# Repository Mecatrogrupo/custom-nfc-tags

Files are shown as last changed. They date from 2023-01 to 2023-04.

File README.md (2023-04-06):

<!--- [![PÁGINA WEB](https://img.shields.io/badge/P%C3%81GINA%20WEB-21759B?style=for-the-badge&logo=WordPress&logoColor=white)](http://mecatrogrupo.com) --->




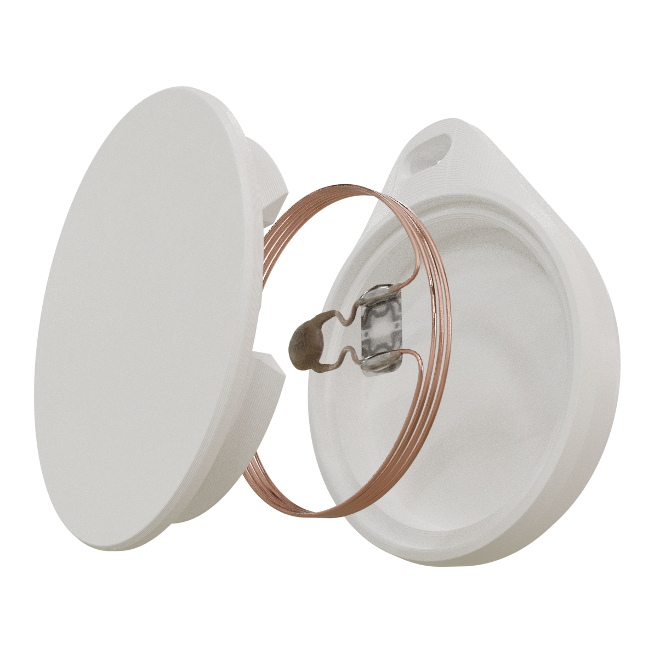
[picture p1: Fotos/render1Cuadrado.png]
Foto explotada llavero


## Objetivo
Lograr convertir diferentes tarjetas NFC dispositivos más pequeños que cumplan las mismas funciónes, como llaveros o pulseras. Esto incluye: extraer los chips y armarles otra carcasa, clonar tarjetas a otros formatos, combinar diferentes tecnologías en una, diseñar métodos para hacerlo en masa, y documentar los hallazgos en general.

## Hallazgos sobre diferentes sistemas
### Transporte argentino
Las tarjetas que usa son del tipo Mifare 1k. Guardan su saldo adentro y, al estar encriptadas, no pueden ser clonadas (o al menos no fácilmente). Su comunicación se define en [ISO 14443](https://www.iso.org/obp/ui/#iso:std:iso-iec:14443:-4:ed-4:v1:en) y trabaja a 13.56MHz. Sin embargo, en la práctica los lectores de transporte oscilan entre 14 y 15 MHz, y hay diferencias pronunciadas entre los diferentes métodos de transporte [[1]](#1).

Las tarjetas pueden ser leídas por teléfonos, pero testear antenas armadas con los mismos no es una buena indicación de la distancia en que las leerá un lector de transporte (por la diferencia de frecuencias y de diámetros del bobinado).

Los chips internos hasta el 2022 venían en dos tamaños: 7,5mm x 5mm y 6mm x 3mm. En 2023 se agregaron unos un poco más grandes.

#### Referencias

<a id="1">[1]</a> 
[ST AN2866 Application note](https://www.st.com/content/ccc/resource/technical/document/application_note/d9/29/ad/cc/04/7c/4c/1e/CD00221490.pdf/files/CD00221490.pdf/jcr:content/translations/en.C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)

## Diseño circular de llavero
Este diseño de llavero se basa en un cuerpo con un disco interno con el chip de la tarjeta, una bobina de cobre esmaltado, y un capacitor. Este último es necesario para lograr que la antena resuene bien a la frecuencia de los lectores, ya que seleccionar el alambre justo con la cantidad de vueltas justa es mucho más difícil y resulta en una distancia de lectura menor. \
Probamos hacer variantes *print in place* (se imprime el cuerpo hasta la mitad y después se coloca el llavero) y no *print in place* (se imprimen por separado y conectan a presión). Encontramos que la segunda es mucho más fácil de armar y no presenta desventajas considerables (solo queda un poquito más grande). \
Hay instrucciones de armado usando el ejemplo de transporte Argentino en [/Manuales/Instrucciones-maker.pdf](/Manuales/Instrucciones-maker.pdf).

### Medias testeadas que funcionan
*foto con las diferentes medidas*

n: cantidad de vueltas \
l: largo del alambre \
d: diámetro del alambre \
D: diámetro de la bobina \
H: altura espacio para bobinado \
h1: grosor de la tapa inferior \
h2: grosor de la tapa superior \
L: distancia de lectura relativa a la original \
F: medida del capacitor

#### Transporte argentino
| n | l | d | D | H | h1 | h2 | L | F |
|---|---|---|---|---|---|---|---|---|
| 7 | ~ 69cm | 0,25 mm | 25mm | ~35mm | 0.6mm | 1.15mm | buena | 39pF |

<hr />
<table border="0px">
<th align="left">
Mecatrogrupo 2022.
</th>
<tr>
<td>
Esta fuente describe Hardware Libre y está licenciada bajo la licencia 
CERN-OHL-W v2
</td>
</tr>
<tr>
<td>
Puede redistribuir y modificar esta documentación y crear productos
que la utilicen bajo los términos del CERN-OHL-W v2 (https:/cern.ch/cern-ohl).
Esta documentación se distribuye SIN NINGUNA GARANTÍA EXPRESA O IMPLÍCITA
GARANTÍA, INCLUIDA LA DE COMERCIABILIDAD, CALIDAD SATISFACTORIA
E IDONEIDAD PARA UN FIN DETERMINADO. Por favor refiérase a la CERN-OHL-W v2
para condiciones aplicables.<br/>
Ubicación de la fuente: https://github.com/Mecatrogrupo/custom-nfc-tags/
</td>
</tr>
</table>

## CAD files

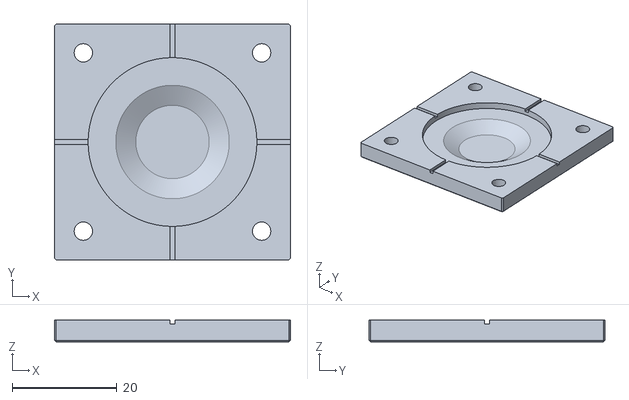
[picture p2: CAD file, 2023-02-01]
Modelos 3D/Sostenedor-de-disco.stl
45.0 x 45.0 x 4.15

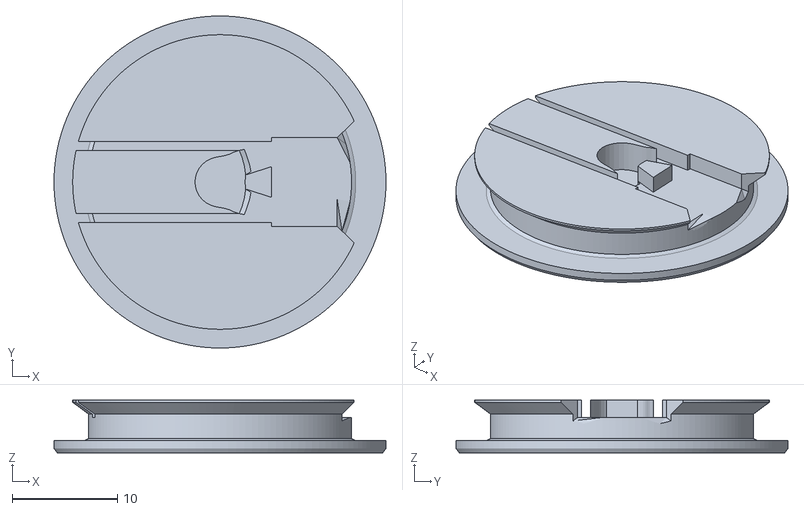
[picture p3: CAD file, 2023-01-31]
Modelos 3D/Disco.stl
31.5 x 31.5 x 4.99

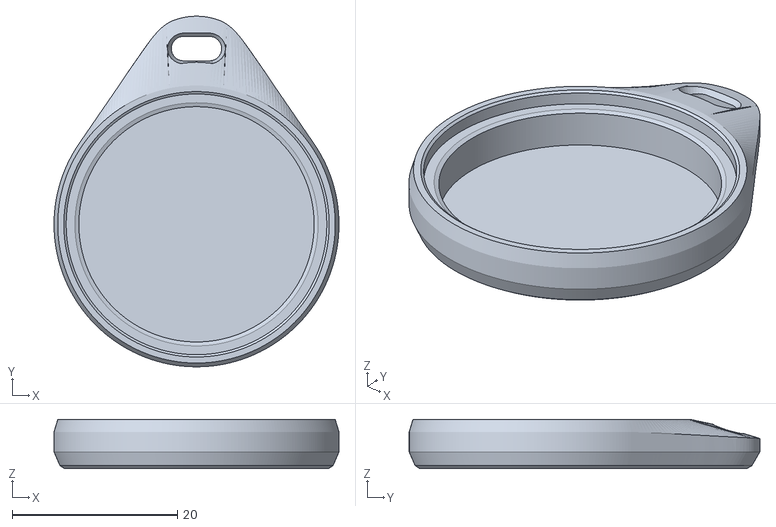
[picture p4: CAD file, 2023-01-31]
Modelos 3D/Cuerpo.stl
34.5 x 42.4 x 5.95

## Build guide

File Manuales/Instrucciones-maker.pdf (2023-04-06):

Llavero de Transporte - Kit Maker

## Instrucciones de armado

# ⓿ PARTES INCLUÍDAS

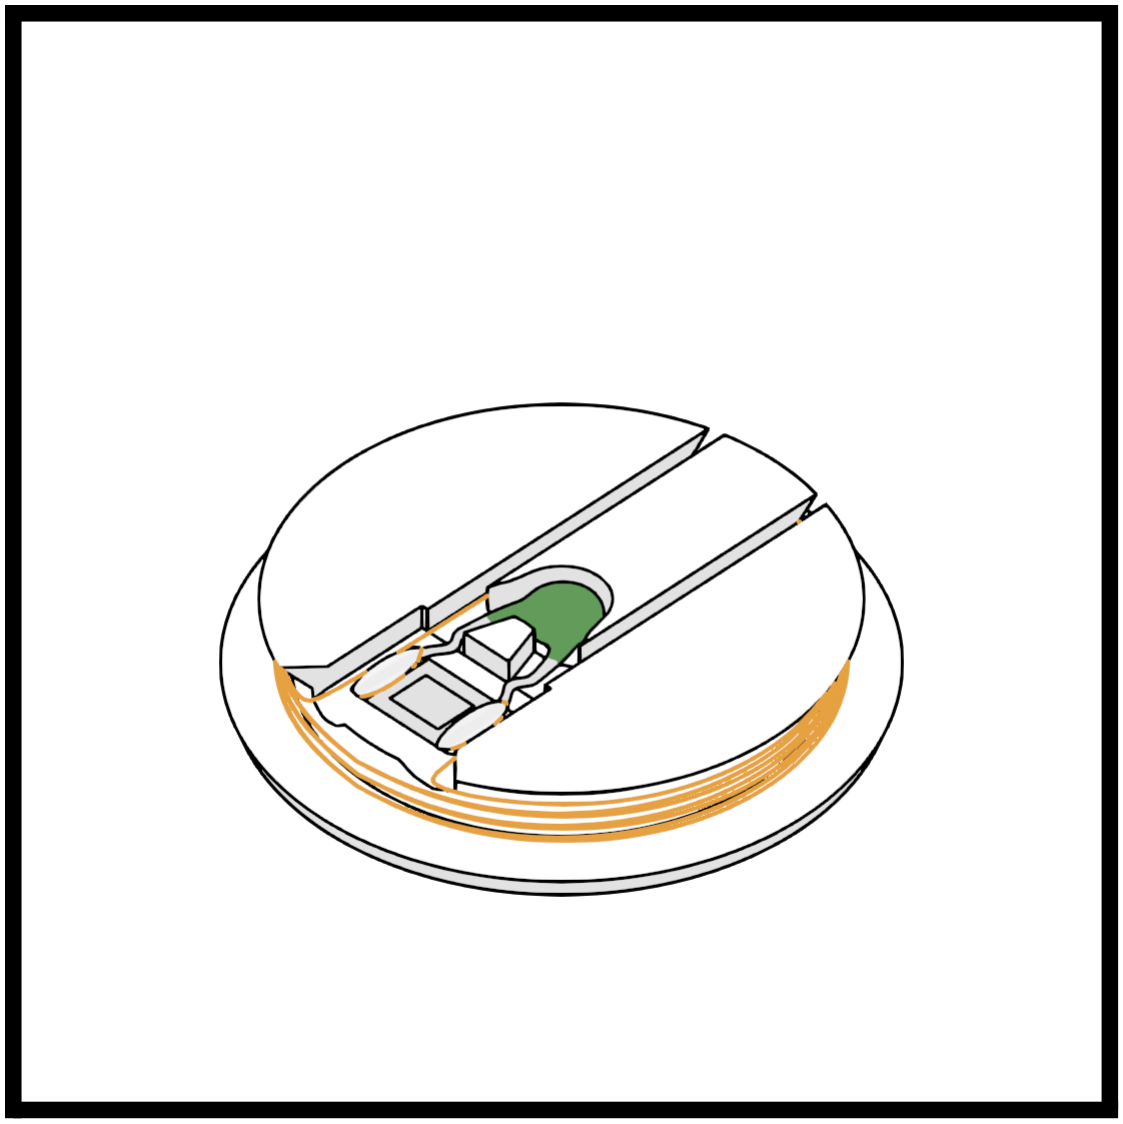
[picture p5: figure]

Disco | Cuerpo | Mosquetón

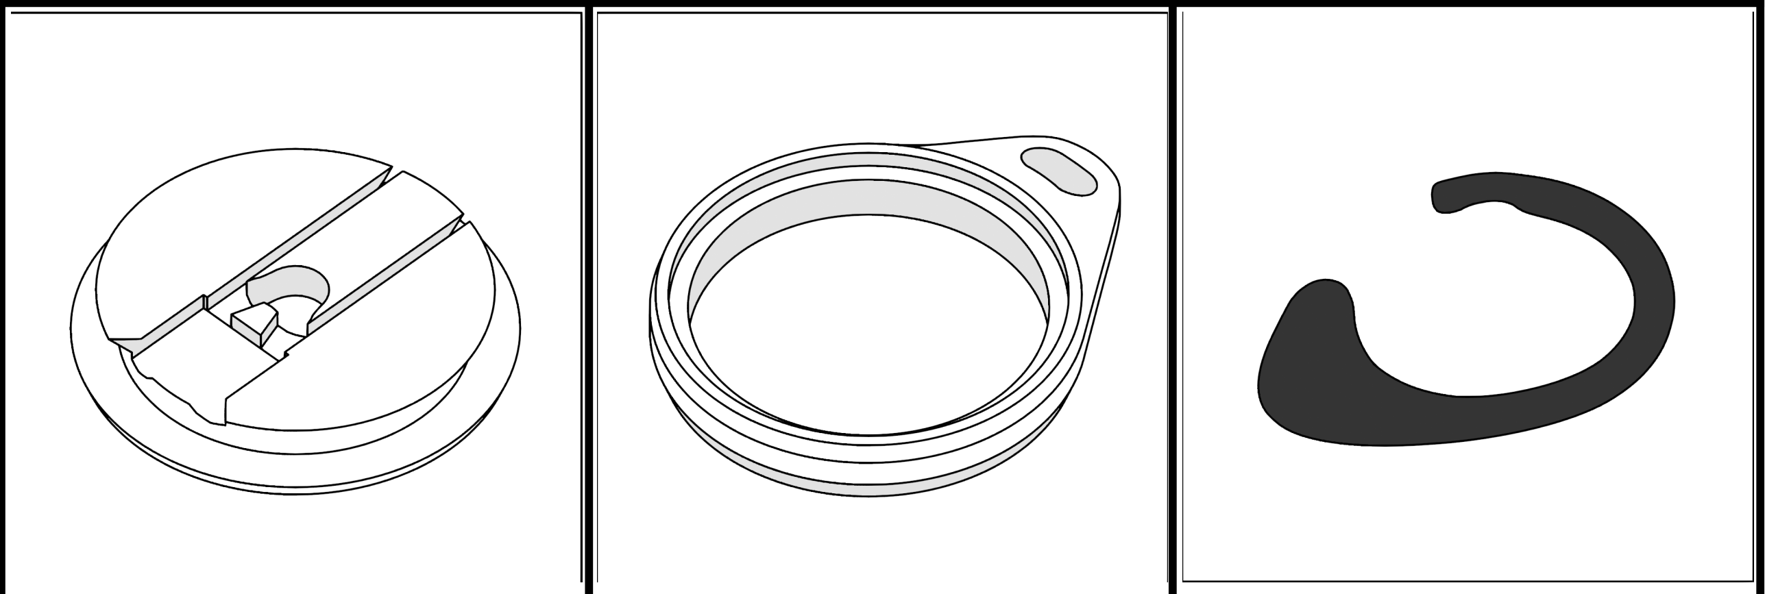
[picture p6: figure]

Cadena | Alambre | Capacitor

1

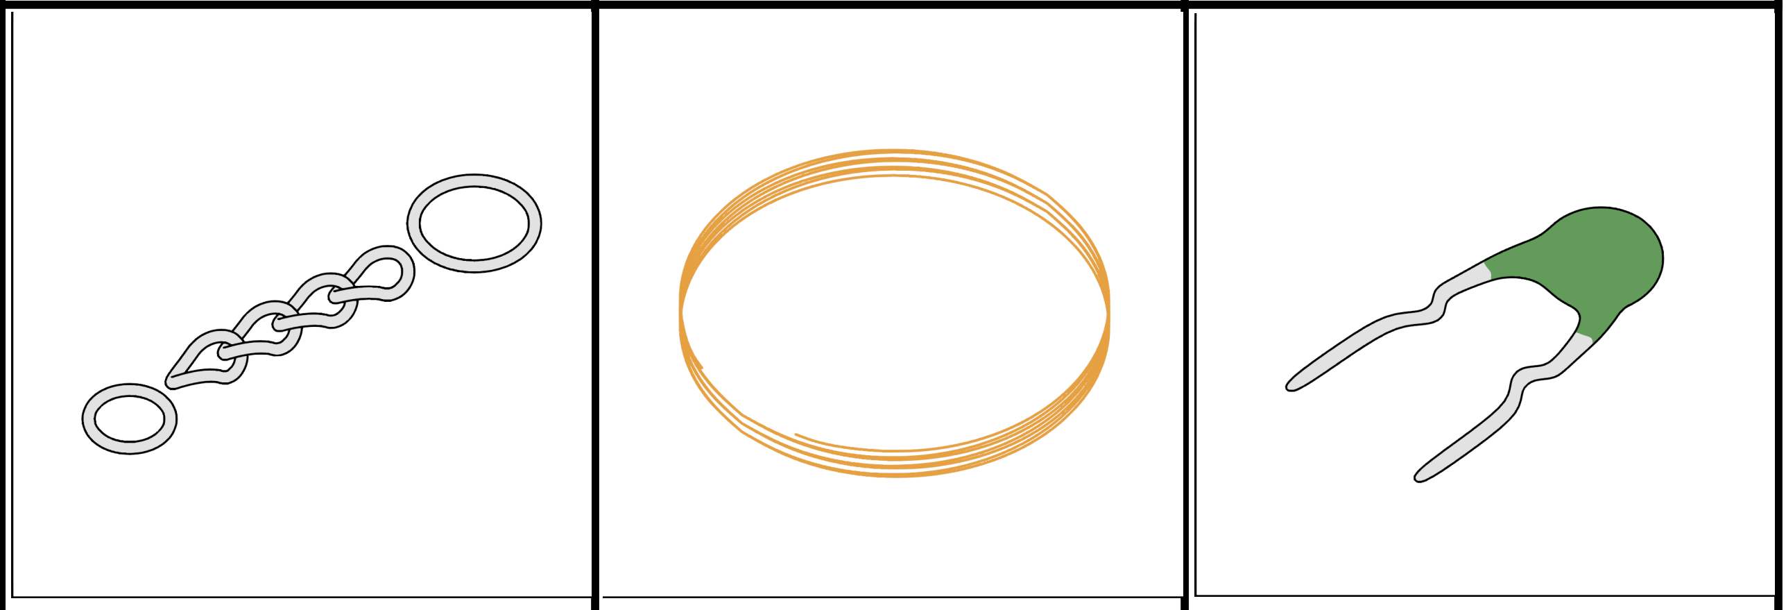
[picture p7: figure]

## Instrucciones de armado

# ❶ EXTRAER EL CHIP DE LA TARJETA

## Ⓐ Preparar la tarjeta

1. Anotar el número de la tarjeta para evitar perderlo
2. Mirar la tarjeta a contraluz con una linterna para encontrar el chip, suele estar en la esquina inferior derecha.
3. Marcar la zona del chip con un marcador.

## Ⓑ Recortar el chip

1. Con una tijera o alicate, cortar el pedazo del plástico donde se encuentra el chip. Hacerlo al ras, ya que alrededor del chip las capas de plástico están menos pegadas.

## Ⓒ Disolver el plástico

1. En un pequeño recipiente de vidrio o metal poner el pedazo de plástico y suficiente disolvente* como para taparlo.
2. Dejar disolver entre 20 mins. y 3 horas, agitando y limpiando residuos cada tanto.
3. Separar el chip con cuidado y sumergirlo en agua para no tocar la acetona.
4. Raspar las patas del chip con algo filoso, para que no quede ningún residuo.
Como disolvente sirven los quitaesmaltes con acetato de etilo, la acetona pura, o cualquier otro disolvente para PVC *

2

## Instrucciones de armado

# ❷ ARMAR LA BOBINA

## Ⓐ Enrollar la bobina

1. Enganchar una punta del alambre a una de las ranuras del disco, extendiéndolo hacia el espacio del chip.
2. Darle 7 vueltas al disco con el alambre, asegurarse que las puntas queden en el lugar donde se va a poner el chip. Trabar la punta del alambre en la segunda ranura.
3. Posicionar el capacitor en su lugar, de manera tal que las patitas traben el alambre para que no se salga.

## Ⓑ Desesmaltar las puntas

Si no tiene experiencia, recomendamos que practique los siguientes pasos con un pedacito sobrante de alambre.
1. Marcar dónde iría el chip para saber hasta donde desesmaltar.
2. Sacar el alambre del disco y quemar con un encendedor las puntas.
3. Lijar la parte quemada hasta que ya no se vea negra.
4. (Opcional) Usar un tester para probar continuidad.

## Ⓒ Estañar las puntas

1. Con un soldador, derretir estaño* en las puntas del alambre. Deberían quedar plateadas.
2. Si el estaño no pega, puede que no estén bien desesmaltadas. Repetir el punto B.

Recomendamos usar estaño con flux *

3

## Instrucciones de armado

# ❸ SOLDAR LOS COMPONENTES

## Ⓐ Preparar los componentes

1. Insertar el chip por debajo de las patas del capacitor.
2. Asegurarse de que las patas del capacitor y las puntas del alambre estén en contacto con los bordes del chip (los pads plateados).

Las patas del capacitor pueden doblarse para que queden en la posición correcta*

## Ⓑ Soldar los componentes

1. Soldar cada lado del chip con su respectiva punta del alambre y pata del capacitor.
2. Probar leer el disco con un teléfono con NFC o una terminal de carga.
3. Si no funciona, volver a soldar.

No apoyar el soldador durante mucho tiempo, ya que puede sobrecalentar los componentes*

4

## Instrucciones de armado

# ❹ ARMAR EL LLAVERO

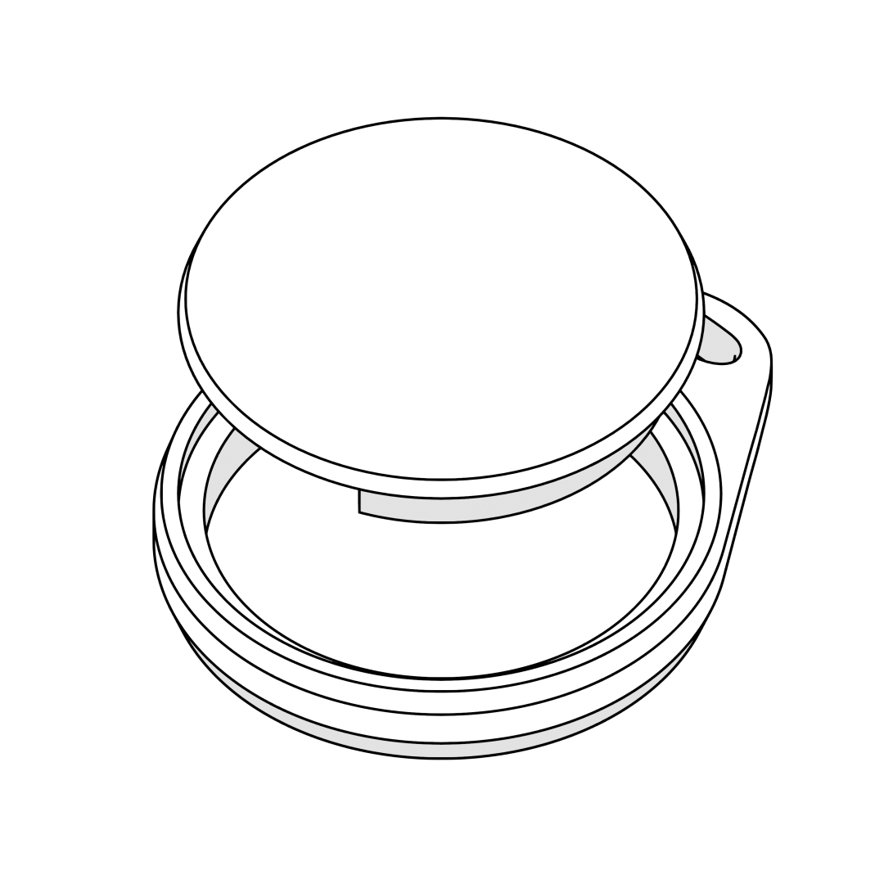
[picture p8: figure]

## Ⓐ Sellar la carcasa

1. (Opcional) Poner pegamento universal en los bordes internos del cuerpo. Si no se sabe la conductividad del pegamento, evitar ponerlo en la zona del chip.
2. Insertar el disco dentro del cuerpo.
3. Aplicar presión hasta notar que el disco no se sale. Puede usarse un martillo y algo más chico que el disco para presionarlo más y hacerlo a prueba de agua.

## Ⓑ Agregar la cadena y el ganchito

1. Con ayuda de una pinzas, armar la cadena (agregándole la argolla grande para enganchar la carcasa, y la argolla chica para el mosquetón).
2. (Opcional

5

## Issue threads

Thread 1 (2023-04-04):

Sugerencia

juliandm101, 2023-04-04:
Hola gente, antes que nada muchas gracias por compartir el proyecto, ya comprè las cosas para hacerlo.
Como sugerencia, estarìa bueno poner en el paso a paso, que antes de cortar la tarjeta original, uno deberia anotar el numero de la misma (o sacarle una foto), antes de tirar todos los pedazos.
Un abrazo!

Mecatrogrupo, 2023-04-06:
Buen día,
Muchísimas gracias por la compra y la recomendación, justo estábamos
actualizando las instrucciones escritas así que nos vino bárbaro. Estamos
tan acostumbrados a leer el llavero con el celu cuando lo terminamos que
nos olvidamos que no todos tienen NFC...
Si te interesa el tema fijate en los próximos días que estamos pensando en
hacer un kit con capacitor variable e instrucciones para convertir
cualquier cosa RFID.
Mecatrogrupo

El mar, 4 abr 2023 a la(s) 20:42, juliandm101 ***@***.***)
escribió:

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

Closed 2023-04-06.

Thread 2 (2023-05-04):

Sugerencia

Tatitooo, 2023-05-04:
Estaría bueno que incluyan información sobre como se podrían realizar los calculos de las vueltas del alambre de cobre (y como lo realizaron ustedes en este caso, el porque), y más información sobre el capacitor y por qué ese en específico. Hay mucha gente que tiene curiosidad por estos proyectos y si bien hay unas instrucciones que seguir explicando los cálculos y mostrandolos podrían entusiasmar a personas a aprender más sobre este tema.

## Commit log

2023-02-01 agregar base para soldar
    [Sostenedor-de-disco.stl]
2023-04-06 Cambiar las instrucciones para agregar #1 , imágenes, materiales y limpiar un poco el texto.
2023-04-06 Eliminar Armado.md.
    Toda su info. ya está en Instrucciones-Maker, así que no nos sirve más
2023-04-06 Update README.md
    Rellenar todos los valores que faltaban
